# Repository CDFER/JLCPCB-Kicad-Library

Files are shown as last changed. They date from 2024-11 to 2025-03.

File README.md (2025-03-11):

# JLCPCB-KiCad-Library



A full KiCad library containing matched schematic symbols and PCB footprints, complete with 3D STEP models. This Library is focused on components from JLCPCB's **basic and preferred** parts list, ensuring no extra setup costs.  I’m not affiliated or sponsored by jlcpcb, just another customer.

## Screenshots

| KiCad | Fusion 360 |
|:---:|:---:|
|3D Component Sample|3D Component Sample in Fusion 360|

| | |
|:---:|:---:|
|Diode Symbol Selection|Buck Converter Symbol Selection|

Schematic Buck

## Features

* Daily updated stock and pricing information (uses Github Actions)
* Minimum order quantity and attrition quantity provided for every component
* Utilizes .step files for seamless SolidWorks and Fusion 360 integration
* 99% of components include 3D models
* Datasheet links
* Supports Bouni's [JLCPCB Tools Plugin](https://github.com/Bouni/kicad-jlcpcb-tools)
* Fully compatible with kicad 8.0+ and 9.0
* Allows you to export price to BOM

## Install using the package manager

Add my custom repository to the Plugin and Content Manager, the URL is:

```
https://raw.githubusercontent.com/CDFER/cd_fer-kicad-repository/main/repository.json
```

Add My Custom Kicad Package Repo

Select My Custom Kicad Package Repo and press install

After adding the repository link, press Save. Then, select CD_FER's KiCad repository from the dropdown menu and click on the JLCPCB KiCad Library. Finally, click the Install button and apply the pending changes.

### Install Guide Video

Thanks to Rob Frohne for putting the time in to make a video to guide you through how to install the library

[**▶️ Watch the Install Guide Video**](https://www.youtube.com/watch?v=Bf6XzcvVBs4)

### Updating the Library

KiCad currently doesn't support fully automatic updates but it does notify you and you then have to manually navigate the installed libraries, click to update it and apply pending changes (yeah it's a bit annoying).

Package Update Warning

Add My Custom Kicad Package Repo

## Notes

* Even though I have tested this library a number of times on pcb orders now, be careful and always check the output footprint and symbol.
* If you notice that anything is wrong or that an important feature is missing, please open an issue or pull request so it can be fixed.

### What is Attrition Quantity?

**Attrition Quantity** is the number of parts that get wasted when setting up the machine (like during adjustments or errors).  

When you order parts, you need to buy **either**:  

1. The **minimum amount** the supplier allows (**JLCPCB’s minimum order quantity**), *or*

2. **Enough for your product** (total parts needed) **+ extra** to cover wasted parts during setup.  

**Example**:  
If you’re making 5 circuit boards, and each needs 10 resistors, you’d need 50 resistors. But if you expect 2 parts to be wasted (attrition), order **52 resistors total** (or the JLCPCB minimum, if it’s higher).  

## Editing this Library (for Pull Requests)

1. Clone this repo to your own machine
2. Install python
3. Setup Python 3.13 .venv with the packages in `requirements.txt` [venv setup guide](venv_setup.md)
4. Run ```libraryCreatorScript.py``` (use the run button in the top right hand corner)
5. Don't commit changes to ```metadata.json``` (release metadata is handled by github actions)
6. Avoid committing changes to automatically generated symbol libraries (avoids conflicts if you just commit changes to the python code)

## License

This library is released under the MIT license

© 2024 Chris Dirks

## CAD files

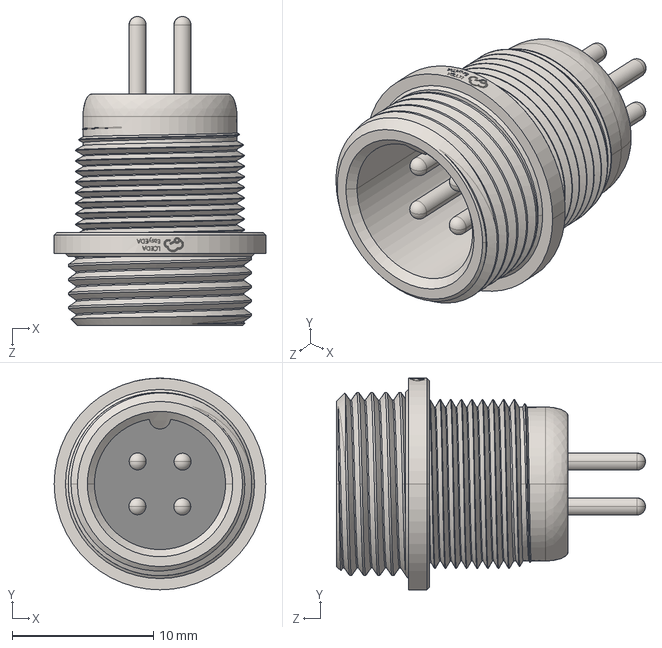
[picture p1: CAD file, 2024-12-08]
JLCPCB-Kicad-Footprints/3dModels/CONN-TH_HKT-00004.step
15.0 x 15.0 x 21.9 mm

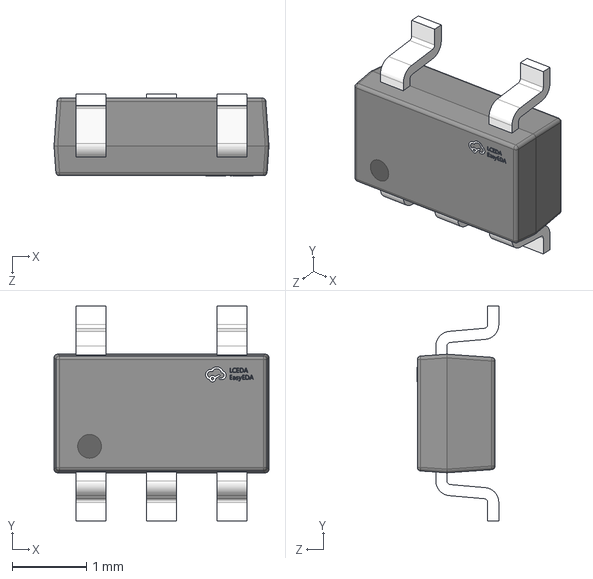
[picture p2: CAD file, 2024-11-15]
JLCPCB-Kicad-Footprints/3dModels/SOT-23-5_L2.9-W1.6-P0.95-LS2.8-BR.step
2.90 x 2.90 x 1.10 mm

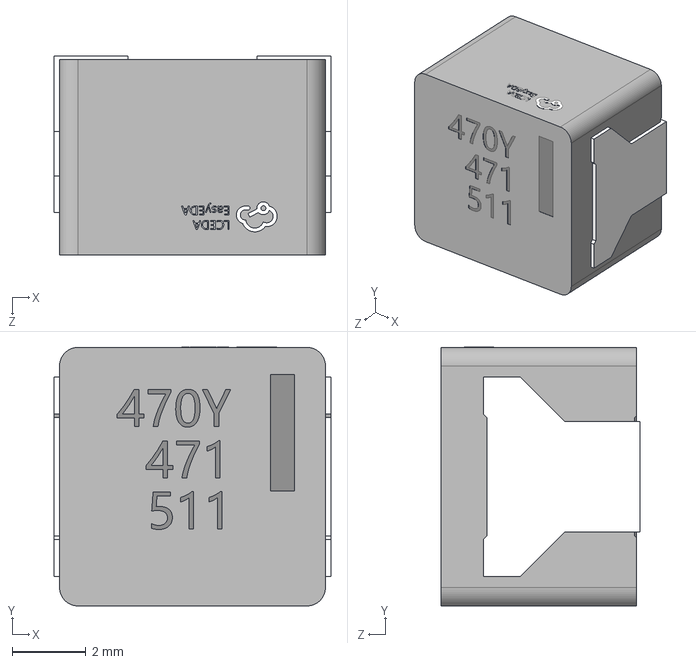
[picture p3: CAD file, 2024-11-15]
JLCPCB-Kicad-Footprints/3dModels/IND-SMD_L7.5-W7.0.step
7.50 x 7.01 x 5.40 mm

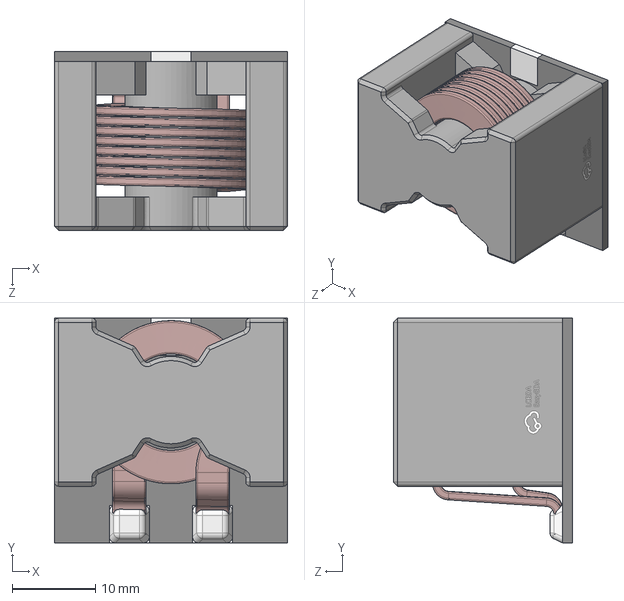
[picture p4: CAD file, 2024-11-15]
JLCPCB-Kicad-Footprints/3dModels/IND-SMD_3P-L28.0-W27.0_1.step
28.0 x 27.0 x 21.5 mm

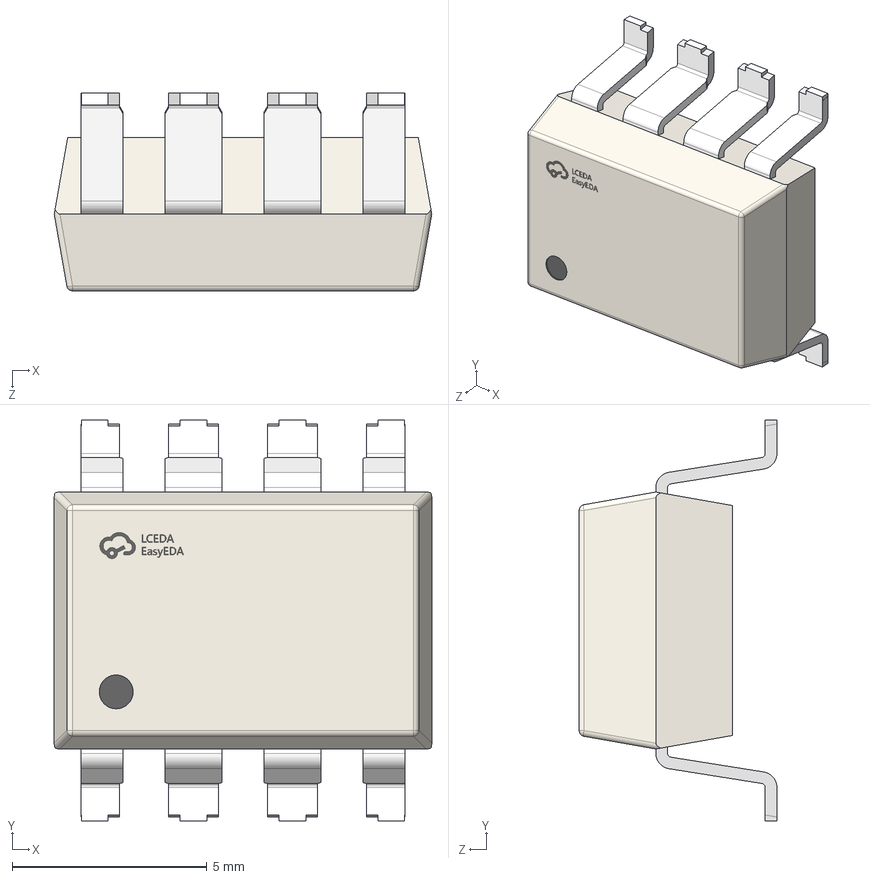
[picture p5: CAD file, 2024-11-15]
JLCPCB-Kicad-Footprints/3dModels/SMT-8_L9.7-W6.6-P2.54-LS10.3-BL.step
9.70 x 10.3 x 5.08 mm

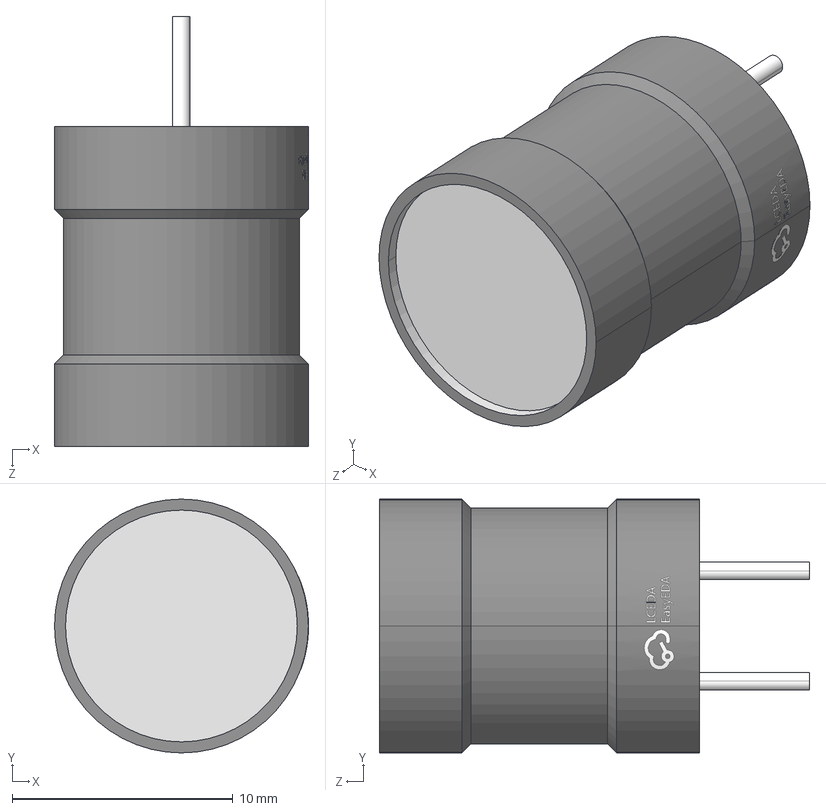
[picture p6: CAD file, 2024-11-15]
JLCPCB-Kicad-Footprints/3dModels/IND-TH_BD11.5-P5.00-D0.8.step
11.5 x 11.5 x 19.5 mm

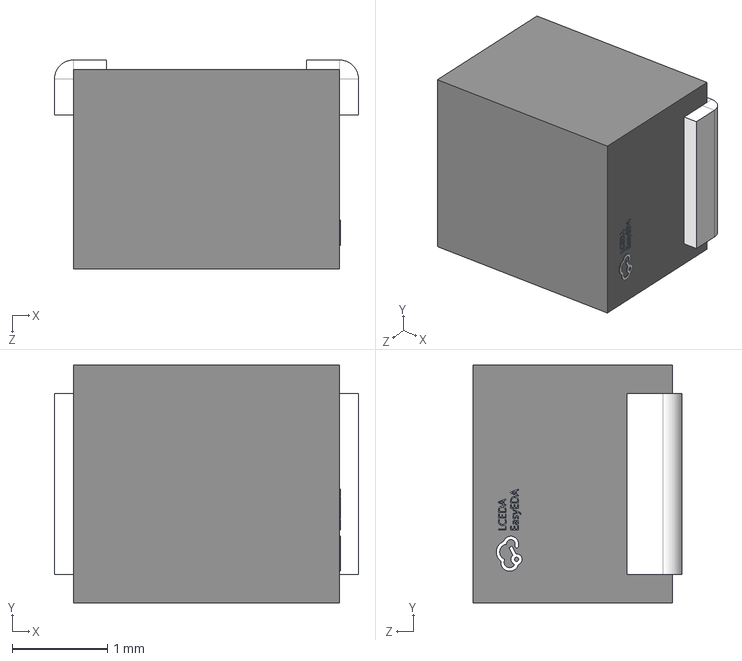
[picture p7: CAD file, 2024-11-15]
JLCPCB-Kicad-Footprints/3dModels/IND-SMD_L3.2-W2.5.step
3.20 x 2.50 x 2.20 mm

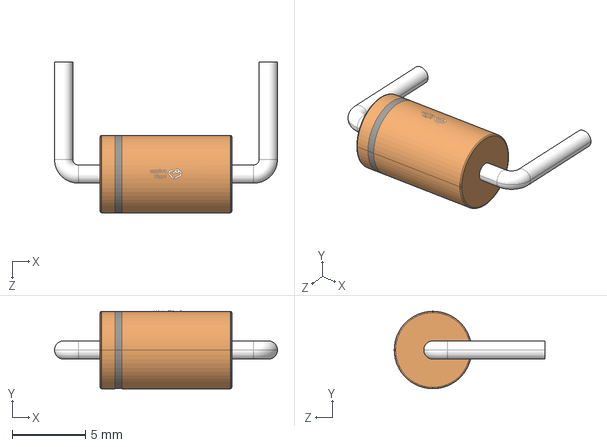
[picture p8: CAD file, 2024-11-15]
JLCPCB-Kicad-Footprints/3dModels/DO-27-BD5.3-L9.0-P14.0-D1.3-R-RD.step
15.2 x 5.30 x 10.3 mm

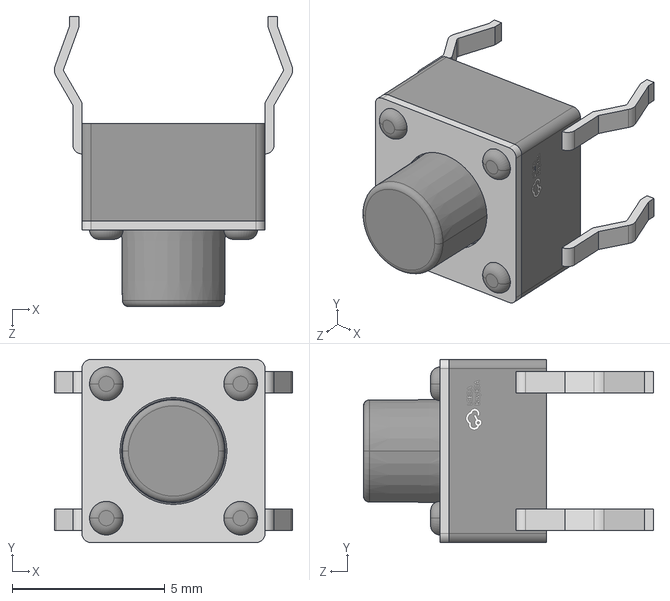
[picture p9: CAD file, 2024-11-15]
JLCPCB-Kicad-Footprints/3dModels/KEY-TH_4P-L6.0-W6.0-P4.50-LS6.50.step
7.80 x 6.00 x 9.50 mm

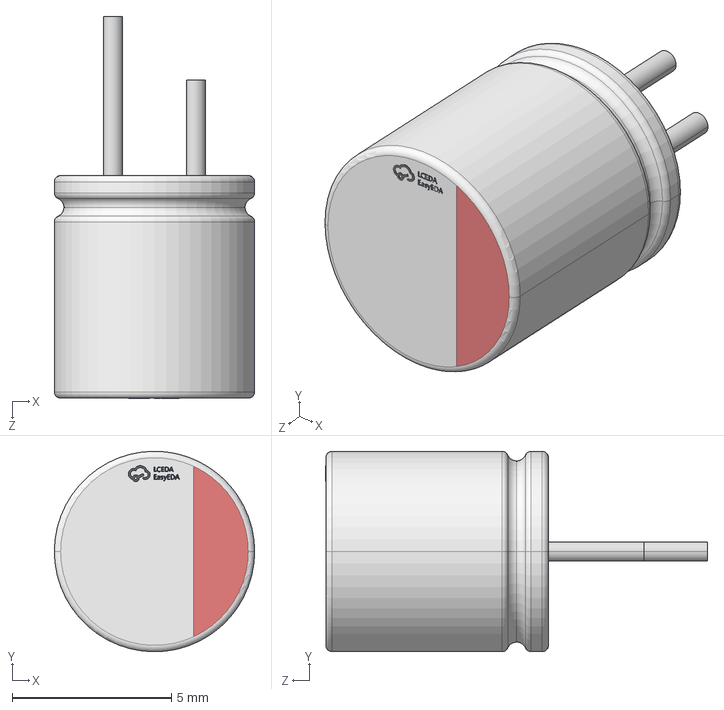
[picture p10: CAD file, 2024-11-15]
JLCPCB-Kicad-Footprints/3dModels/CAP-TH_BD6.3-P2.60-D0.6-FD-1.step
6.30 x 6.30 x 12.0 mm

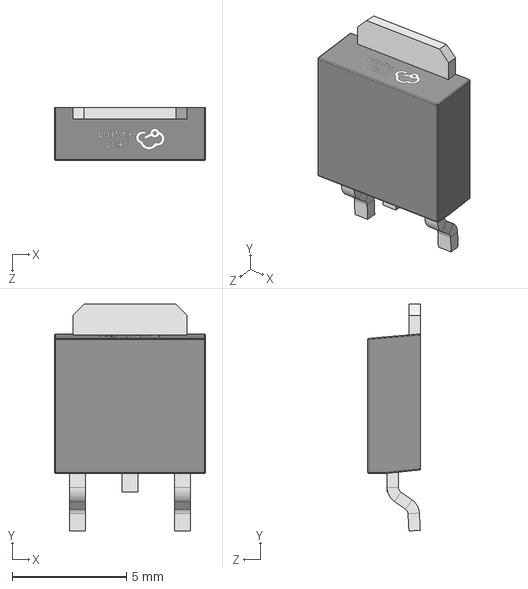
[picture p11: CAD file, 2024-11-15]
JLCPCB-Kicad-Footprints/3dModels/TO-252-2_L6.6-W6.1-P4.57-LS9.9-BR-CW.step
6.60 x 9.92 x 2.30 mm

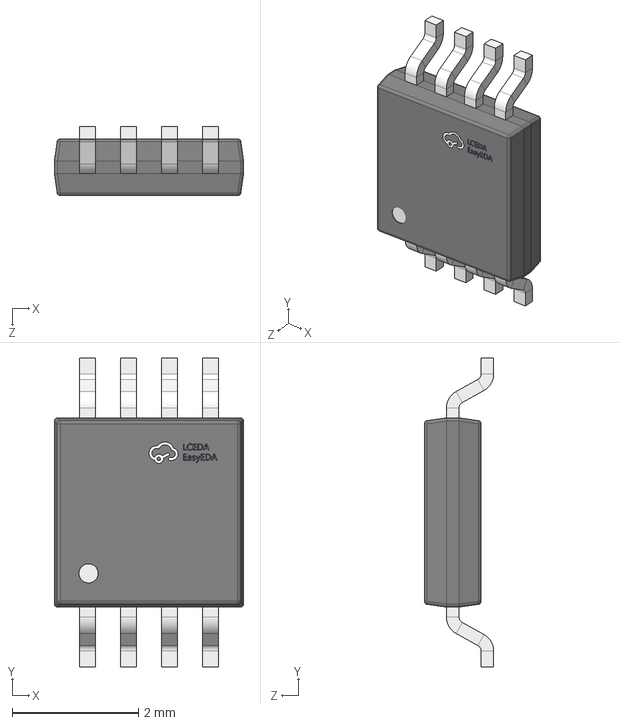
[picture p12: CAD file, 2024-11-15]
JLCPCB-Kicad-Footprints/3dModels/MSOP-8_L3.0-W3.0-P0.65-LS4.9-BL.step
3.00 x 4.90 x 1.10 mm

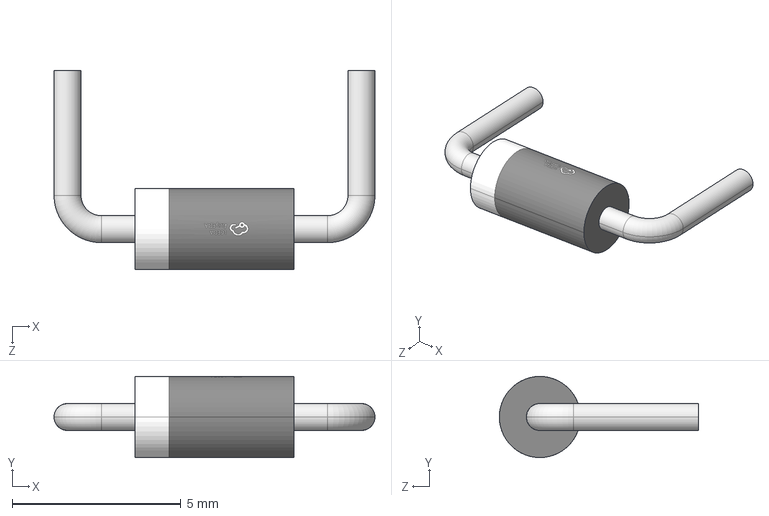
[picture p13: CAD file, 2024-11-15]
JLCPCB-Kicad-Footprints/3dModels/DO-41_BD2.4-L4.7-P8.70-D0.6-RD.step
9.50 x 2.40 x 5.90 mm

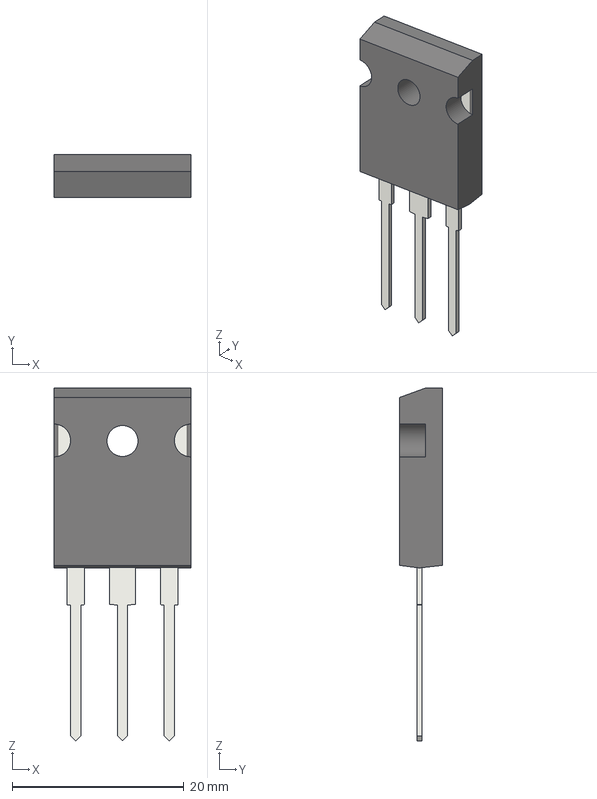
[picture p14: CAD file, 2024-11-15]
JLCPCB-Kicad-Footprints/3dModels/TO-247-3_Vertical.step
15.9 x 5.03 x 41.1 mm

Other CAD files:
JLCPCB-Kicad-Footprints/3dModels/CAP-TH_BD8.0-P3.50-D0.6-FD_1.step
JLCPCB-Kicad-Footprints/3dModels/RES-SMD_L10.0-W5.2.step
JLCPCB-Kicad-Footprints/3dModels/SDB_L8.3-W6.4-P5.10-LS9.9-BL.step
JLCPCB-Kicad-Footprints/3dModels/IND-SMD_L13.8-W12.6_YSPI13XX.step
Archived-Symbols-Footprints/JLCPCB-Kicad-Footprints/3dModels/AUDIO-TH_PJ-3850-5A.step
Archived-Symbols-Footprints/JLCPCB-Kicad-Footprints/3dModels/BAT-TH_BS-07-A1BJ001.step
Archived-Symbols-Footprints/JLCPCB-Kicad-Footprints/3dModels/CAP-SMD_BD8.0-L8.3-W8.3-FD.step
Archived-Symbols-Footprints/JLCPCB-Kicad-Footprints/3dModels/CAP-SMD_L7.3-W4.3-L-FD.step
Archived-Symbols-Footprints/JLCPCB-Kicad-Footprints/3dModels/CAP-TH_BD10.0-P5.00-D0.6-FD-A.step
Archived-Symbols-Footprints/JLCPCB-Kicad-Footprints/3dModels/CAP-TH_BD10.0-P5.00-D0.6-FD.step
Archived-Symbols-Footprints/JLCPCB-Kicad-Footprints/3dModels/CAP-TH_BD13.0-P5.00-D0.6-FD.step
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

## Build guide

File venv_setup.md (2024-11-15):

## Setting up a Python Virtual Environment (.venv) with Jupyter Notebooks in VSCode

### Step 1: Install Python and VSCode

1. Install Python https://www.python.org/downloads/
2. Install VSCode https://code.visualstudio.com/Download

### Step 2: Install Required Extensions in VSCode

1. Open VSCode.
2. Install the "Python" extension by Microsoft.
3. Install the "Jupyter" extension by Microsoft.

### Step 3: Create a Virtual Environment (.venv)

1. Open the `libraryCreatorScript.ipynb` file in VSCode.
2. Select a kernel using the kernel picker in the top right.
	Select a kernel using the kernel picker in the top right
3. Click "Select another Kernel".
4. Click "Python Environments".
5. Click "Create Python Environment".
6. Click "Venv".
7. Click "Create New".

### Step 4: Verify the Virtual Environment

Run the first cell on `libraryCreatorScript.ipynb` and it should download all the needed packages without any errors in less than 30s.


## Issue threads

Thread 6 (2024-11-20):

C_0805.kicad_mod double courtyard

Rockstein2, 2024-11-20:
this leads to DRC errors

CDFER, 2024-11-21:
Not sure how that got in there, fixed by https://github.com/CDFER/JLCPCB-Kicad-Library/commit/285825b7fc855d3da76826b9ce4c2d848f2ad78c

Thx :)

Closed 2024-11-21.

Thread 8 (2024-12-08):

Extended & archived components

vapoto, 2024-12-08:
First of all thank you very much for this project, it is an incredible time saver when designing a PCB for production by JLCPCB!

I was using the vertical USB-C connector with 14 pins (C2982529), but this seems to have been moved to the archived components in the library. I assume this is because it is an extended part? However, there is also a JLCPCB-Extended (sub)library in this project. Could you explain how the selection for this is done?

It would be great to have all extended parts available (maybe in a separate folder/library), but I understand this might not be feasible because of computational and API limits. Would there be a way though for users to specify a list of extended parts and locally create a library for them in the same way as you are doing?

CDFER, 2024-12-08:
To address your question about the USB-C connector (C2982529): JLCPCB occasionally changes which components are categorized as basic/preferred. For example, C2982529 was moved to the extended parts list on December 2nd ([see here](https://github.com/CDFER/jlcpcb-parts-database/blob/d7e695b20299d4b0330be322caf139cecf7c7b28/scraped/ComponentList.csv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)).

Currently, the library moves components that are no longer basic/preferred to the archive folder, along with their footprints and 3D models. If you're still looking for this part, you can find it [here](https://github.com/CDFER/JLCPCB-Kicad-Library/blob/main/Archived-Symbols-Footprints/JLCPCB-Kicad-Symbols/2982529.kicad_sym).

Regarding the "JLCPCB-Extended" sublibrary, it currently includes extended parts that I commonly use. However, adding all 300,000+ components isn’t feasible as KiCad wouldn’t handle that many symbols well, and there are no stock/price updates for extended components at the moment. That said, I may eventually integrate the most popular 1,000 or so extended components based on how quickly stock data decreases.

Unfortunately, generating symbols/footprints fully automatically isn’t possible yet, as I do a lot of manual reworks to improve quality (source EasyEDA files are often less than ideal). Adding user-specified components would require improvements to pull data directly from the SQLite file (which I’m considering for the future).

For now, if there are specific extended components you'd think would be useful, let me know and I'll do my best to add them!

Closed 2024-12-12.

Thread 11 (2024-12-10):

[Bug] Footprint Library doesn't load without being renamed to JLCPCB-Kicad-Footprints.pretty

CDFER, 2024-12-10:
>
> The Footprint LIB need to end in .pretty I think. I needed to add it to Kicad with that extension to get it to work for me. Great job though!
>

u/[ignorpicus](https://www.reddit.com/user/ignorpicus/) on r/[KiCad](https://www.reddit.com/r/KiCad/comments/1h9t7b3/just_finished_writing_automatically_updated_kicad/)

CDFER, 2024-12-10:
>  Huh, I didn't know that but yeah you are right. It works without that for me (Kicad 8.0, Windows 11 22H2) but all of the KiCad libraries are like that and the package manager requires that structure https://dev-docs.kicad.org/en/addons/index.html
>
> Unfortunately that is a breaking change so maybe I'll add that in the next major update (Someone also pointed out that it should be KiCad not Kicad in the folder names).

CDFER, 2024-12-12:
> Windows (latest) and 8.x

Closed 2025-01-12.

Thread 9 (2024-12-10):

README: Proper capitalization is "KiCad", not "Kicad"

DeflateAwning, 2024-12-10:
Just wanted to point out this minor inconsistency!

This is super awesome. I'm really excited to give it a try!

CDFER, 2024-12-10:
Good spoting I'll change the easy stuff soon but unfortunately changing the folder names would be a breaking change I may do it in the next major update when I change the footprint library to .pretty https://github.com/CDFER/JLCPCB-Kicad-Library/issues/11

DeflateAwning, 2024-12-10:
That all sounds great, thank you! :)

Closed 2025-01-12.

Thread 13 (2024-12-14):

Feature Request: Make this library installable via the KiCad extension manager

DeflateAwning, 2024-12-14:

CDFER, 2024-12-14:
This is something I've been thinking about, but I don't think KiCad would allow it in the normal package repository (https://gitlab.com/kicad/addons/repository) due to some of the files being pulled from EasyEDA and the copyright/API access issues that come with that, which KiCad is strict about (https://dev-docs.kicad.org/en/addons/). That being said, I could create my own third-party repository or ask Bouni to join his (https://github.com/Bouni/bouni-kicad-repository), which he uses for his tools here: https://github.com/bouni/kicad-jlcpcb-tools

Being able to press a button in KiCad to update the library would be very handy, so this is pretty high on my to-do list when I get some time.

DeflateAwning, 2024-12-14:
I figure it's worth a shot submitting it to the official KiCad one? And just see what they think? I don't think JLCPCB/LCSC/EasyEDA has much of a history of litigation. And this project doesn't explicity re-distribute; it just uses it as an "inspirational data source" of sorts.

CDFER, 2025-01-12:
Installing via the package manager has been added in V3 that I have just released. For now I am using my own package repository hosted here: https://github.com/CDFER/cd_fer-kicad-repository but I'll be talking to KiCad and Bouni soon :)

Closed 2025-01-12.

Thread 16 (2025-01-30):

NE5532DR Power Connections Won't Connect....e

frohro, 2025-01-30:
I couldn't make the NE5532 power connections to actually connect, so I edited the Symbol and now they do.  I'll add my edited version here in case that helps.  I added the .txt so GitHub would allow me to upload it.

[op-amp, ne5532dr.kicad_sym.txt](https://github.com/user-attachments/files/18596053/op-amp.ne5532dr.kicad_sym.txt)

Closed 2025-01-31.

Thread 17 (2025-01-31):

Questions:  Does the plugin update the database automatically when you start Kicad anew?

frohro, 2025-01-31:
I like this plugin!  One of the pain points of designing hobby PCBs for JLCPCB fabrication has been finding parts and footprints from JLCPCB.  They should give you a big donation!  I do have some questions that would be nice if they were answered clearly in the README.

1. Does the plugin automatically update the database every time Kicad is started?
  a) If not, how do we update it?

Thanks!

Rob

frohro, 2025-02-03:
I made a video about installing this library.  It is [here](https://www.youtube.com/watch?v=Bf6XzcvVBs4).

Closed 2025-02-06.

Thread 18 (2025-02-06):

0805 Footprint Errors

frohro, 2025-02-06:
Hi,
The 0805 footprints you are using have a "malformed courtyard."

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

Thanks for fixing all these things!

Rob

CDFER, 2025-02-07:
Thanks for spotting this, it really helps to get rid of those rough edges that I have missed :)

I've gone through and fixed all the DRC errors I can find in the footprints here: https://github.com/CDFER/JLCPCB-Kicad-Library/commit/b3a3518cb78484469e243446e26005330055260b

It'll be out in the release later today.

One thing I still need to work on is standardizing how the courtyard is sized across the footprints (not all that useful to most people but pretty handy if you use auto-placement in tools like TopoR)

frohro, 2025-02-07:
Thanks Chris!

frohro, 2025-02-09:
They appear good now Chris!

Closed 2025-02-09.

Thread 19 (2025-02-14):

Capacitors not loaded fully

jaxonjaxon, 2025-02-14:
When I search in Symbol Chooser for "22uf" I got results only for about 10 capacitors. When I do the same on jlcpcb parts website, I get over 2 pages of results.

I'm using Kicad 8.0 and loaded the library today using extension manager/GUI download.
Please correct me if I'm doing something wrong

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

CDFER, 2025-02-19:
This Library is focused on the Basic/Prefered Parts not the whole extended JLCPCB Parts List (would be over 300,000 components and KiCad can't really handle that many). If you have any extended components that are particularly useful I am open to suggestions to add to the extended library folder (PCM_JLCPCB-Extended).

Closed 2025-02-20.

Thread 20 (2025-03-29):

C5446 Part symbol has Vin and Vout pins swapped.

vsch, 2025-03-29:
The part has wrong pinout on the symbol. It is an LDO 3.3V regulator and the symbol has Vin and Vout swapped. From the datasheet (https://jlcpcb.com/api/file/downloadByFileSystemAccessId/8579707861620228096):
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

JLCPCB part page <https://jlcpcb.com/partdetail/TorexSemicon-XC6206P332MRG/C5446> shows the right EasyEDA symbol,
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

however JLCPCB-Kicad-Library and importing from EasyEDA using the `easyeda2kicad` tools, results in the wrong pinout also.

JLCPCB-Kicad-Library:

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

easyeda2kicad:

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

I can confirm this from 10 PCBs that I ordered and the 3.3V supply was not working. Swapping the pins corrected the problem. I now have to do this for the other 9 PCBs.

CDFER, 2025-03-31:
Thank you for reporting this issue—and especially for including detailed references (datasheet, JLCPCB links, and screenshots). You’re absolutely right: the symbol in both the JLCPCB-Kicad-Library and easyeda2kicad output incorrectly swaps Vin and Vout. I’ve verified this against the datasheet and confirmed the discrepancy.

Next Steps:
* Fix the Library: I’ve corrected the symbol in the library and it will be pushed out in the update later today.
* I've gone through the JLCPCB-Power Library by hand and checked all the symbols (I found that C3113 was wroing too)
* I have put together a quick bit of code to find other errors using deepseek R1 and I will pulish this soon along with any fixes that I need to made once it has finished processing (it takes an hour to and it's running rn)
* When I have time (or if someone else has the time to do it before me) we should go through the other libraries based on easyeda2kicad these are:
```
 -Analog
 -Connectors_Buttons
 -Crystals
 -Diode-Packages
 -ICs
 -Inductors
 -Interface
 -MCUs
 -Memory
 -Transistor-Packages
```

I’m sorry this caused issues with your PCBs—I appreciate you taking the time to flag it so others won’t run into the same problem. Going forward I'm going to go through and double check all the footprints from easyeda2kicad with thier respective data sheets. Let me know if you spot anything else :)

CDFER, 2025-03-31:
Issue for easyeda2kicad.py:  uPesy/easyeda2kicad.py/issues/156
JLC2KiCad_lib also has the same issue too: TousstNicolas/JLC2KiCad_lib/issues/83

Closed 2025-04-17.

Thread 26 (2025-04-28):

DP9900 series of POE modules appear to be missing

jharvey, 2025-04-28:
There are a series of POE modules which would be great to have in the library. I guess extended parts are not the primary goal. It would be great to see these module added to the library?
https://jlcpcb.com/partdetail/Sdapo-DP9900M5V/C5380106

jharvey, 2025-04-28:
If it helps, here's a symbol which works for the DP990X series, and a footprint which works for the DP9900M series.
-- The symbol and footprint were made by converting a EasyEDA file to KICAD, using online converter tools.
-- 3d Step file was made by me using OnShape and MFG datasheet. I can make the DP9900LP series if there is interest.
I release this under what ever open source license is preferred.

[DP990.zip](https://github.com/user-attachments/files/19938473/DP990.zip)

CDFER, 2025-04-28:
Cool, I'll add it when I get some free time. I just need to convert it to KiCad 8 so we maintain bacwards compatability :)

jharvey, 2025-04-29:
In the next week or so I'll have a couple more components. Looks like an ETH jack and an ETH transformer. Any suggestion on things I can do with those components to help? I'll try doing it in KC8, then use that lib file in my KC9 project.

jharvey, 2025-04-30:
@CDFER
I changed the issue description. Also please see attached, an ETH connector, an ETH transformer, and a POE module. These include symbol, footprint, and 3D files. I only made 3D of the DP9900M, all other files are imports from EasyEDA with light manipulation.

[KC8.zip](https://github.com/user-attachments/files/19969921/KC8.zip)

jharvey, 2025-04-30:
Hmmm, how to convert the KC9 backwards into KC8. My KC9 symbols are much nicer then the KC8's imported from EasyEDA. I'll attempt to convert the KC9's to KC8's tomorrow.

jharvey, 2025-04-30:
I found a way to convert. In EasyEDA I imported a KC file, then I exported to Altium, then I opened that with KC8. If you open KC8 eeschema.exe manually, not via project launch pad, it allows you to open files. Then I did a bit of cleanup, and now have the files attached. Anyhow see below KC8 files converted from my KC9 files.
[KC8_from_KC9.zip](https://github.com/user-attachments/files/19974745/KC8_from_KC9.zip)

jharvey, 2025-05-03:
Here's another one. It's a rectifier used in POE circuit. It was drafted in KC8.

[MB6S.zip](https://github.com/user-attachments/files/20022542/MB6S.zip)

jharvey, 2025-05-03:
Another connector, this if for an OV2640 or OV5640 camera. This was exported from EasyEDA, and I'm relying on the pinout from here https://github.com/maxlab-io/tokay-lite-pcb
[ov2640-ov5640_CAMERA-CONNECTOR.zip](https://github.com/user-attachments/files/20023097/ov2640-ov5640_CAMERA-CONNECTOR.zip)

jharvey, 2025-05-03:
Also these symbols. Same as the 3.3V version, but for 2.8V and 1.5V. This was sourced from the existing CDFER library.

[XC6206_symbols.zip](https://github.com/user-attachments/files/20023577/XC6206_symbols.zip)

jharvey, 2025-05-04:
Here's another one. It's a 7 segment display driver, Symbol / footprint exported from EasyEDA, 3D is KICAD original.
[digital tube drivers_c2962580.zip](https://github.com/user-attachments/files/20026989/digital.tube.drivers_c2962580.zip)

jharvey, 2025-05-04:
A red 7 segment LED display 3 characters wide. The symbol, footprint and 3D exported from EasyEDA
[3x7-seg_LED-RED_C2913084.zip](https://github.com/user-attachments/files/20027095/3x7-seg_LED-RED_C2913084.zip)

@CDFER Should I  be doing this in separate issues, or is doing this all in 1 issue an OK place to relay the files?

jharvey, 2025-05-04:
This is an audio chip, Exported from EasyEDA, 3D is KICAD OEM.
[MAX98357AETE+T.zip](https://github.com/user-attachments/files/20028516/MAX98357AETE%2BT.zip)

jharvey, 2025-05-06:
I found a problem with several of the symbols I posted above. Several need a rotation to prevent issues when sent to JLCPCB. I'll update those in the next couple of days. I'm also not happy with my inconsistent naming convention. I plan to change these 2 things and re-upload a new version of the symbols / footprints.

I tried following the pull request guidelines, but I was not successful in the validation step of setting up VSCode.

jharvey, 2025-05-07:
@CDFER  I just took a stab at a pull request. I'm not a GH guru. Let me know if something is out of place. I think it should be good. I'd suggest double checking the 3D and the footprint are linked correctly. For some reason my PC has an issue with certs and I used the GH clone repo instead of the plugin manager repo. This may have potentially caused some linking issues, but I think I got it all proper.
-- Files were made with KC8
-- Some files use KC 3D
-- Most files were exported from EasyEDA. I made a couple symbols with more detail. I noted those with KC. They are kind of duplicates of the EDA simple version.
-- 3D was mostly exported from EaseEDA, lightly manipulated in onshape. I created one model from the MFG datasheet.

I'll remove the above zip files and extra posts. I think those are just going to cause confusion at this point.

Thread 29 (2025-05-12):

JLC part rotation issues for PCM_JLCPCB:Q_SOT-23

jharvey, 2025-05-12:
Hello,

When I place LCSC C15127 it uses footprint PCM_JLCPCB:Q_SOT-23. Fab files were generated via Plugin tool "fabrication toolkit" https://github.com/sponsors/bennymeg version 5.0.1 and uploaded to JLCPCB. When I do I get a rotation issue as noted in this picture.

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

The 3D files in KICAD appear to be in good order. It's just a problem with JLC files.

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

I'm having this with a couple other packages as well. I plan to put in a new issue for each footprint. I'm assuming you would prefer individual issue trackers for each footprint.

My JLCPCB KiCad Library is Version 2025.05.12

CDFER, 2025-06-01:
merged into https://github.com/CDFER/JLCPCB-Kicad-Library/issues/30

Closed 2025-06-01.

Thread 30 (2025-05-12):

JLC part rotation issues for PCM_JLCPCB:SOIC-8_L5.3-W5.3-P1.27-LS8.0-BL

jharvey, 2025-05-12:
Hello,

When I place LCSC C97521it uses footprint PCM_JLCPCB:SOIC-8_L5.3-W5.3-P1.27-LS8.0-BL. Fab files were generated with plug in tool and uploaded to JLCPCB. Then I get a rotation issue as noted in this picture.

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

The 3D files in KICAD appear to be in good order. It's just a problem with JLC files.

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

I'm having this with a couple other packages as well. I plan to put in a new issue for each footprint. I'm assuming you would prefer individual issue trackers for each footprint.

My JLCPCB KiCad Library is Version 2025.05.12
Plugin tool "Fabrication Toolkit" https://github.com/sponsors/bennymeg version 5.0.1
KiCad V9.0.2
Windows 10.

CDFER, 2025-06-01:
I've merged your two issues. Here is your other issue:

Hello,

When I place LCSC C15127 it uses footprint PCM_JLCPCB:Q_SOT-23. Fab files were generated via Plugin tool "fabrication toolkit" https://github.com/sponsors/bennymeg version 5.0.1 and uploaded to JLCPCB. When I do I get a rotation issue as noted in this picture.

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

The 3D files in KICAD appear to be in good order. It's just a problem with JLC files.

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

I'm having this with a couple other packages as well. I plan to put in a new issue for each footprint. I'm assuming you would prefer individual issue trackers for each footprint.

My JLCPCB KiCad Library is Version 2025.05.12

CDFER, 2025-06-01:
Thanks for reporting this issue and including detailed examples :)

### **Root Cause**
The rotation mismatch occurs because JLCPCB’s assembly process uses a different **coordinate system** and **rotation reference** compared to KiCad. While the 3D models in KiCad appear correct, some footprints in this library (especially those adapted from EasyEDA) have orientation that conflict with JLCPCB’s expectations. The Fabrication Toolkit plugin assumes native KiCad footprints, so non-standard rotations in modified/EasyEDA-derived footprints can cause misalignment in the generated CPL files.

---

### **Solutions Under Consideration**
1. **Rotation Mapping File**
   - Create a `.csv` file to manually override rotations for problematic footprints (compatible with [kicad-jlcpcb-tools](https://github.com/Bouni/kicad-jlcpcb-tools)).
   - **Pros**: Immediate fix for existing footprints.
   - **Cons**: Requires users to import the file for every project.

   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

2. **Transition to Native KiCad Footprints**
   - Gradually replace EasyEDA-derived footprints with KiCad-native ones to ensure compatibility.
   - **Pros**: This already slowly happening to get away from large mesh in .step 3dfiles that easyEDA sometimes uses.
   - **Cons**: Time-intensive; some footprints (e.g., JLC-specific parts) will need to be recreated from scratch.

---

### **Short-Term Workaround**
- For urgent projects, manually adjust rotations in the CPL file or JLCPCB’s assembly interface.
- Use **Bouni’s kicad-jlcpcb-tools** with a custom rotation file.

---

### **Next Steps**
- I’ll prioritize fixing the **SOIC-8** and **SOT-23** footprints you flagged.
- If you encounter other problematic parts, just add them to this issue

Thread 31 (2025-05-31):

Missing capacitor

ClovisLd, 2025-05-31:
I'm new to PCB making so I dont know if I should just edit the value of the component on the shematics but I wanted to use 22µF tantalum capacitor but the only one I found were 100µ and 10µ. Am I doing something wrong or are the just missing ?

P.S. I have just seen a previous issues abotu the same topic and you aksed about useful component to add an I think 22uF tantalum capacitor are a good idea since they are often used with these type of regulator such as AMS1117 -3.3 (https://www.lcsc.com/datasheet/lcsc_datasheet_2410121508_Advanced-Monolithic-Systems-AMS1117-3-3_C6186.pdf)

ClovisLd, 2025-06-01:
could you explain to me how to add a part from jlc Part library website to my project library

CDFER, 2025-06-20:
I would recomend you take a look at [https://github.com/uPesy/easyeda2kicad.py](https://github.com/uPesy/easyeda2kicad.py)

Closed 2025-06-20.

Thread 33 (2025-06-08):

Basic part (button) missing

neopostmodern, 2025-06-08:
This part is Basic but it doesn't show up in the library: https://jlcpcb.com/partdetail/Xunpu-TS_1088AR02016/C720477
(This one – the other basic part button – does though: https://jlcpcb.com/partdetail/XkbConnection-TS_1187A_B_AB/C318884)

This is the concerned file where it should be: https://github.com/CDFER/JLCPCB-Kicad-Library/blob/main/symbols/JLCPCB-Connectors_Buttons.kicad_sym

frohro, 2025-06-11:
I miss this too!

frohro, 2025-06-20:
Thanks Chris!

Closed 2025-06-20.

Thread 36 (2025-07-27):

Do not see jlcpcb resistors in KiCad

mate0327, 2025-07-27:

mate0327, 2025-07-29:
Thanks! Now it works. Seems you fixed something. Package manager was installing me a newer version, but now it is fine.

thomas-maurice, 2025-07-29:
Excellent, I'll try that later, my stop gap fix was to download a working zip and installing it directly from file, thanks a lot for the fix :)

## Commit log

2023-08-13 fix footprint broken links
2023-08-13 add 18650 holder add cr1220 holder add RJ45 add rotary encoder
2023-08-13 Tidy up footprints
2023-08-13 add GPS antenna 25 x 25
2023-08-14 added courtyards to footprints
2023-08-14 fixed 3d model footprints
2023-08-14 fix footprint offsets change to kicad default footprints for standard smd components add 18650 battery holder model
2023-08-25 fixed esp32s2
2023-12-15 improved footprints (#3)
    * improved footprints
    * optimize footprints and improve naming
    * add mouseBites
    fix 0603 LED position for picknplace
    * SOIC grid alignment
    ---------
2024-11-15 V2.0 (#5)
    * Gitignore files larger than 100MiB (JLCPCB sqlite parts database)
    * setup automatic resistor and capacitor libraries
    * Add diodes and Transistors
    * add more footprints, bugfixes
    * add inductors
    add transistor footprints
    add more diode footprints
    remove 0201 components
    fix LEDs
    change handling of missing footprints
    * add handmade library support (only for MCUs rn)
    move auto symbol generation to it's own .py file
    * add inductor and ferrite symbols
    add STM8S105K6T6C
    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
    [ANT-TH_L25.0-W25.0.step, AUDIO-TH_PJ-3850-5A.step, BAT-TH_BS-07-A1BJ001.step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]
2024-11-15 Apply automatic changes
    [TO-252-2_L6.6-W6.1-P4.57-LS9.9-BR-CW.step]
2024-11-16 - Fix Transistor Pinouts - Change to using newer datasheets - Combine SOT-89 Footprints
    [SOT-89-3_L4.5-W2.5-P1.50-LS4.0-BR-1.step]
2024-11-19 - Rewrite Handmade Symbol Property generation - Add MOQ, Attrition Qty, Assembly Process - Improve Price Calculation - Standardize python formatting - Remove empty properties
    [DO-247_L15.6-W5.0-P10.90.step]
2024-11-21 - Fix C_0805.kicad_mod double courtyard - Add missing components (C7722)
2024-12-08 - add missing components - tweak readme - tweak github action run time - tweak print out of errors - tweak footprints, symbols
    [CONN-TH_HKT-00004.step, SOT-363-6_L2.2-W1.3-P0.65-LS2.1-BL.step]
2024-12-12 Hotfix for JLCPCB Changing "Plugin" to "插件" in footprints
    [CAP-TH_BD10.0-P5.00-D0.6-FD-A.step, CAP-TH_L13.0-W7.0-P10.00-D0.6.step, CAP-TH_L26.5-W10.0-P22.50-D0.8.step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]
2024-12-14 Fix Kicad Spelling
2024-12-16 add new LED values
2025-01-12 V3 (#15)
    * Kicad Default Library Structure
    * Update Footprint & Model Links
    * Fix footprint linking
    * Add package icon
    * Update library creation code
    * Fix JLCPCB Manufacturing footprint links
    * Add package metadata
    * Update Readme
    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
2025-01-18 Fix Footprint Linking
2025-01-20 Enable Footprint and Model checks
2025-01-28 Allow install on KiCad 6.0+
2025-01-31 Fix pins that aren't on the 1.27mm grid (https://github.com/CDFER/JLCPCB-Kicad-Library/issues/16)
2025-02-10 Add missing Transistors
    [SOT-363-6_L2.2-W1.3-P0.65-LS2.1-BL.step]
2025-02-23 Add Hongjiacheng TVS Diodes
2025-03-11 Update readme for KiCad 9 and add some pointers for pull requests
2025-03-31 Manually fix the power symbols for errors
2025-04-01 Fix easyeda pinswaps (#21)
    * Minor fixes to crystals and connectors
    * Fix Symbol pinswaps and small fixes
    * Add pinswap LLM Check Code
2025-06-20 Fix Button Footprints

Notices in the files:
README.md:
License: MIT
